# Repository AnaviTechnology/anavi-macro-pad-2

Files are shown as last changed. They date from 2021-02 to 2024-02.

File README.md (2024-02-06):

# ANAVI Macro Pad 2

**Open source, programmable, two-key keypad with backlighting**

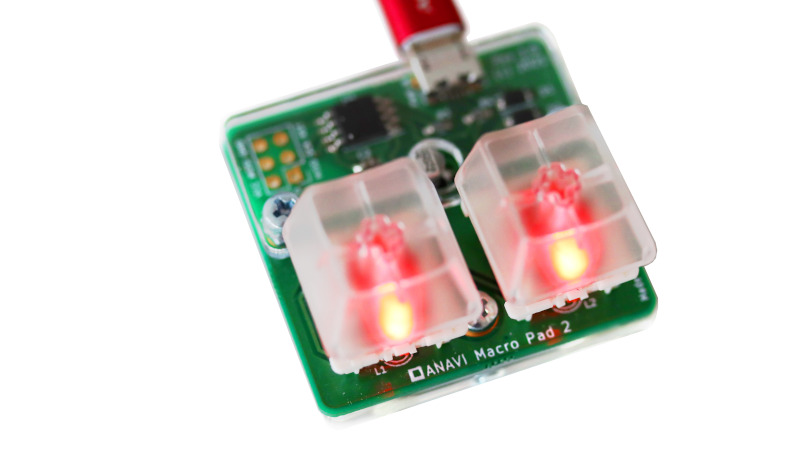
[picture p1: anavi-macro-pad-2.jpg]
ANAVI Macro Pad 2


ANAVI Macro Pad 2 is an open source, custom-programmable, mini 2-key keyboard/keypad. Each key can be reprogrammed to activate a macro or even a dedicated shortcut - all without any coding experience! Powered by the advanced, but easy-to-use [Quantum Mechanical Keyboard (QMK) open source firmware](https://github.com/qmk/qmk_firmware/tree/master/keyboards/anavi/macropad8).

ANAVI Macro Pad 2 has been designed with [the cross platform and open source electronics design automation suite KiCad](https://kicad.org/). [The acrylic enclosure](https://github.com/AnaviTechnology/anavi-cases/tree/master/anavi-macro-pad-8-case) has been designed with [OpenSCAD](https://www.openscad.org/).

For more details please visit https://anavi.technology/

# License

The project is released under the [Creative Commons Attribution-ShareAlike 4.0 International (CC BY-SA 4.0)](https://creativecommons.org/licenses/by-sa/4.0/).

Note: This is a human-readable summary of (and not a substitute for) the [license](https://creativecommons.org/licenses/by-sa/4.0/legalcode).

You are free to:

Share — copy and redistribute the material in any medium or format Adapt — remix, transform, and build upon the material for any purpose, even commercially. The licensor cannot revoke these freedoms as long as you follow the license terms. Under the following terms:

Attribution — You must give appropriate credit, provide a link to the license, and indicate if changes were made. You may do so in any reasonable manner, but not in any way that suggests the licensor endorses you or your use. ShareAlike — If you remix, transform, or build upon the material, you must distribute your contributions under the same license as the original. No additional restrictions — You may not apply legal terms or technological measures that legally restrict others from doing anything the license permits. Notices:

You do not have to comply with the license for elements of the material in the public domain or where your use is permitted by an applicable exception or limitation. No warranties are given. The license may not give you all of the permissions necessary for your intended use. For example, other rights such as publicity, privacy, or moral rights may limit how you use the material.

You will have to provide a link to the original creator of the project http://www.anavi.technology on any documentation or website.

Credit can be attributed through a link to the creator website: http://www.anavi.technology

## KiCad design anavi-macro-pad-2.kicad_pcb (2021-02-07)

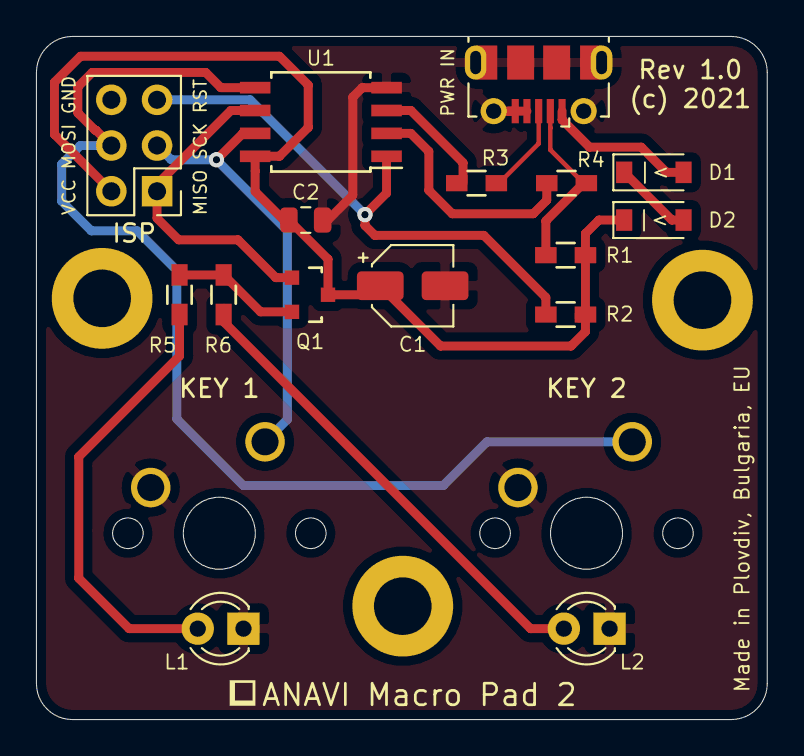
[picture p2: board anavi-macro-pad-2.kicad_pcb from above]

Board: 2 copper layers, 40.6 x 38.0 mm, 18 parts (0 on the bottom side), 15 nets.

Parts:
C1: 10uF; CP_Elec_4x5.4
C2: 100nF; C_0805_2012Metric
D1, D2: 1N4148; D_SOD-123
ISP: AVR-ISP-6; PinHeader_2x03_P2.54mm_Vertical
J1: USB_B_Micro; USB_Micro-B_Molex-105017-0001
KEY 1, KEY 2: SW_DIP_x01; SW_Cherry_MX_1.00u_PCB
L1, L2: LED; LED_D3.0mm
Q1: Q_NPN_BEC; SOT-23
R1: 1.5K; R_0603_HandSoldering
R2: 10k; R_0603_HandSoldering
R3, R4: 22R; R_0603_HandSoldering
R5, R6: 68R; R_0603_HandSoldering
U1: ATtiny85-20SU; SOIJ-8_5.3x5.3mm_P1.27mm

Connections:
GND: C1.2, C2.2, ISP.6, J1.4, J1.5, J1.6, KEY 1.2, KEY 2.2, L1.1, L2.1, U1.4
unnamed: C1.1, C2.1, D2.1, ISP.2, Q1.3, R1.2, R2.1, U1.8
unnamed: D1.1, D2.2
unnamed: D1.2, J1.1
unnamed: J1.2, R1.1, R4.2
unnamed: J1.3, R3.2
unnamed: ISP.1, Q1.1, U1.6
unnamed: ISP.3, KEY 1.1, U1.7
unnamed: ISP.4, KEY 2.1, U1.5
unnamed: ISP.5, R2.2, U1.1
unnamed: L1.2, R5.1
unnamed: L2.2, R6.1
unnamed: Q1.2, R5.2, R6.2
unnamed: R3.1, U1.3
unnamed: R4.1, U1.2

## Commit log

2021-01-31 Add KiCad project
    Add files for the KiCad project.
    [anavi-macro-pad-2.kicad_pcb, anavi-macro-pad-2.sch]
2021-01-31 anavi-macro-pad-2.kicad_pcb: Adjust label
    Adjust C2 label position.
    [anavi-macro-pad-2.kicad_pcb]
2021-02-01 anavi-macro-pad-2.kicad_pcb: Minor adjustments
    Minor adjustments of the front silkscreen.
    [anavi-macro-pad-2.kicad_pcb]
2021-02-07 anavi-macro-pad-2.kicad_pcb: Update silkscreen
    Update the silkscreen:
    - Replace 5V with VCC on the ISP connector because if measured
    when the board is booted from the microUSB it will be about
    3.6-3.7V because of diodes D1 and D2.
    - Remove the white frames around the keys
    - Replace labels K1 and K2 with KEY 1 and KEY 2
    - Increse size and adjust positions of L1 and L2 labels
    [anavi-macro-pad-2.kicad_pcb]
2024-02-06 README.md: Fix KiCad URL

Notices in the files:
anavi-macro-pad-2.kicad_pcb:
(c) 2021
